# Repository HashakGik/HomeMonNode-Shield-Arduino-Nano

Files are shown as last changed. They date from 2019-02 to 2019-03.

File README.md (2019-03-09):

HomeMon Node Shield for Arduino Nano
====================================

This Eagle layout can be used to etch a single HomeMon node, in the form of a shield for the Arduino Nano prototyping platform.

The Arduino Nano sketch for this shield is available [here](https://github.com/HashakGik/HomeMonNode-Shield-Arduino-Nano).

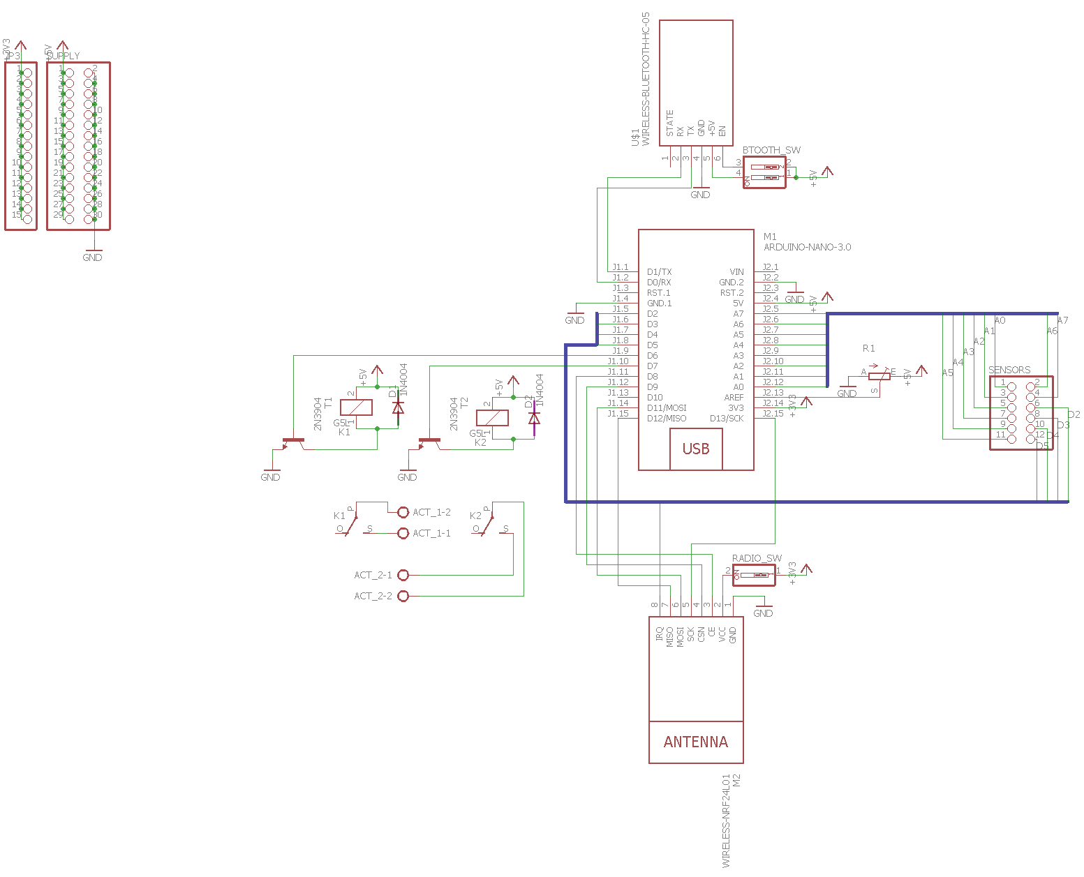
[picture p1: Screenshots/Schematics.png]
Schematics Electric scheme

<br />
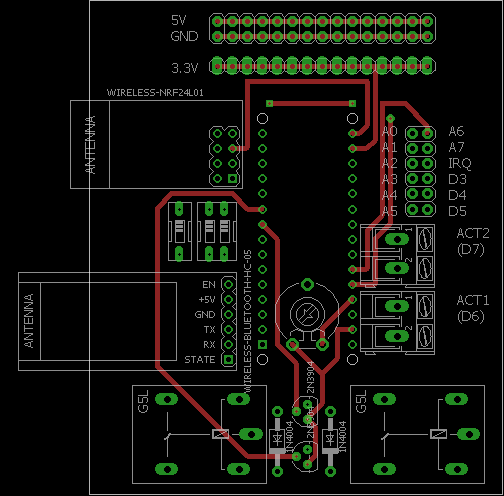
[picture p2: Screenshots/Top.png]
Top PCB Layout - Top side

<br />
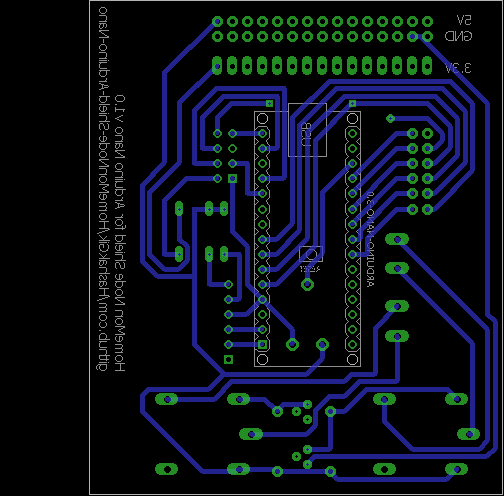
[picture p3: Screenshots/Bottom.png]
Bottom PCB Layout - Bottom side


Features
--------

- Eleven pins can be used as general I/O (e.g. for reading data from sensors)
- Two actuators can be driven by relays
- A power supply bus (5V, 3.3V and ground lines) with fifteen pins is added for convenience
- An [NRF24L01+ 2.4 GHz transceiver](https://www.nordicsemi.com/Products/Low-power-short-range-wireless/nRF24-series) is used for inter-node communication, and serial communication (either via the USB converter of the Arduino or, **optionally**, via an [HC-05 based Bluetooth adapter](https://cdn.makezine.com/uploads/2014/03/hc_hc-05-user-instructions-bluetooth.pdf) allows the node to be connected to a desktop sink running the [HomeMon Viewer Application](https://github.com/HashakGik/HomeMon-MFC-Cpp)
- A trimmer can be used to set the analog voltage reference
- Both the 2.4 GHz transceiver and the optional Bluetooth adapter can be turned on/off by switches (the Bluetooth adapter can additionally be put into AT mode for configuration purposes).

Pinout
------

- Serial pins (`D0` and `D1`): Bluetooth adapter
- SPI pins (`D11` to `D13`), `D2`, `D8` and `D9` pins: radio transceiver
- Analog pins (`A0` to `A7`): directly connected to the `SENSORS` connector
- Digital pins `D2` to `D5`: directly connected to the `SENSORS` connector. (Important note: pin `D2` is also connected to the `IRQ` pin of the transceiver)
- Digital pins `D6` and `D7`: connected to the actuator connectors (`ACT1` and `ACT2` respectively) through two relays
- `AREF`: connected to the analog reference trimmer
- `GND`, `3V3` and `5V`: connected to the power supply connectors
- `RST`, `VIN` and `D10`: unconnected.

Bill of materials
-----------------

- 1x 10k linear trimmer
- 1x Arduino Nano
- 2x Diodes with DO-41 package (e.g. 1N4004)
- 1x DIP switch SPST 1 position (RS-Components code: 877-2100)
- 2x Monostable 5V DC G5LE relays (RS-Components code: 808-8465)
- 2x NPN transistors with TO-92 package (e.g. 2N3904)
- 1x NRF24L01+ module (8 pins breakout board)
- 2x Two-ways PCB terminal blocks with 5.08mm pitch (RS-Components code: 425-8720)

Optionally, for Bluetooth support:

- 1x DIP switch SPST 2 positions (RS-Components code: 877-2113)
- 1x HC-05 Bluetooth module (6 pins breakout board)

Remarks
-------

- The shield relies on the Arduino for power supply (i.e. it doesn't have batteries nor a DC connector, energy must be supplied from the USB connector or the `VIN` pin)
- Arduino pin `D10 (SS)` is left unconnected because the SPI library may malfunction if the pin is set to high when the Arduino is acting as SPI master
- The additional components are defined in the freely available [DIYmodules.org component library](https://www.diymodules.org).

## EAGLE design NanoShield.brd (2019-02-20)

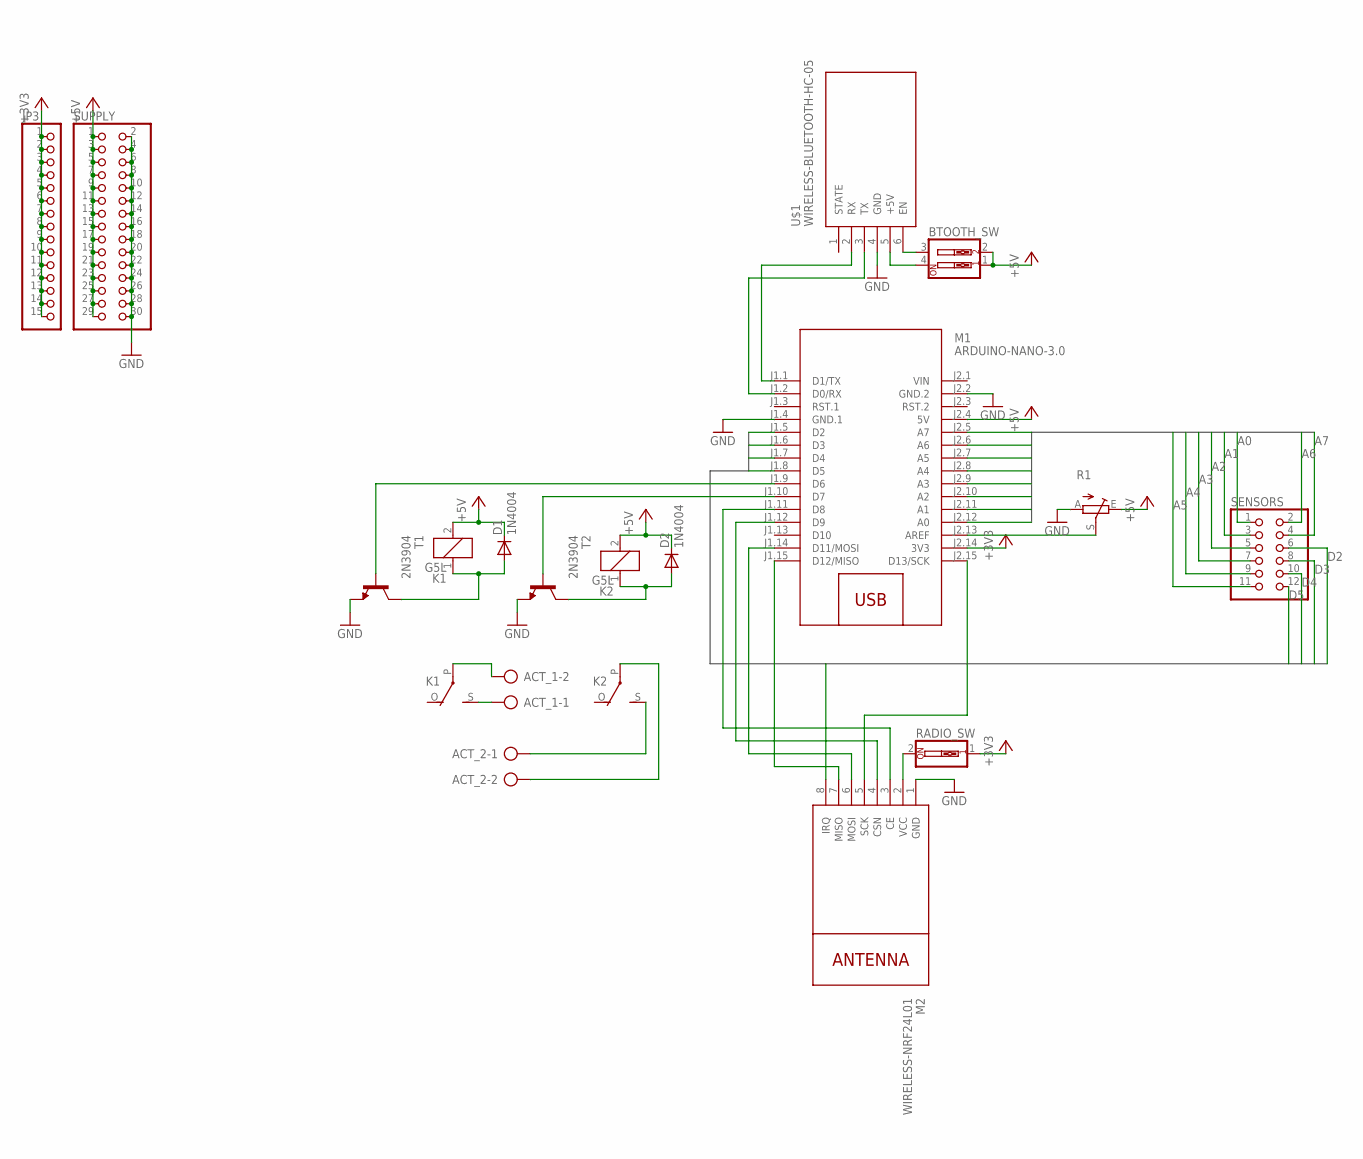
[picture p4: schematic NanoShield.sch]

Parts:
ACT_1, ACT_2: AK300/2
BTOOTH_SW: SW_DIP-2; EDG-02
D1, D2: 1N4004; DO41-10
JP3: PINHD-1X15; 1X15
K1, K2: G5L; G5LE
M1: ARDUINO-NANO-3.0
M2: WIRELESS-NRF24L01
R1: TRIM_EU-LI10; LI10
RADIO_SW: SW_DIP-1; EDG-01
SENSORS: PINHD-2X6; 2X06
SUPPLY: PINHD-2X15; 2X15
T1, T2: 2N3904; TO92
U$1: WIRELESS-BLUETOOTH-HC-05

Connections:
+3V3: JP3.1, JP3.2, JP3.3, JP3.4, JP3.5, JP3.6, JP3.7, JP3.8, JP3.9, JP3.10, JP3.11, JP3.12, JP3.13, JP3.14, JP3.15, M1.J2.14 (3V3), RADIO_SW.1
+5V: BTOOTH_SW.1, BTOOTH_SW.2, D1.C, D2.C, K1.2, K2.2, M1.J2.4 (5V), R1.E, SUPPLY.1, SUPPLY.3, SUPPLY.5, SUPPLY.7, SUPPLY.9, SUPPLY.11, SUPPLY.13, SUPPLY.15, SUPPLY.17, SUPPLY.19, SUPPLY.21, SUPPLY.23, SUPPLY.25, SUPPLY.27, SUPPLY.29
A0: M1.J2.12 (A0), SENSORS.1
A1: M1.J2.11 (A1), SENSORS.3
A2: M1.J2.10 (A2), SENSORS.5
A3: M1.J2.9 (A3), SENSORS.7
A4: M1.J2.8 (A4), SENSORS.9
A5: M1.J2.7 (A5), SENSORS.11
A6: M1.J2.6 (A6), SENSORS.2
A7: M1.J2.5 (A7), SENSORS.4
D2: M1.J1.5 (D2), M2.8 (IRQ), SENSORS.6
D3: M1.J1.6 (D3), SENSORS.8
D4: M1.J1.7 (D4), SENSORS.10
D5: M1.J1.8 (D5), SENSORS.12
GND: M1.J1.4 (GND.1), M1.J2.2 (GND.2), M2.1 (GND), R1.A, SUPPLY.2, SUPPLY.4, SUPPLY.6, SUPPLY.8, SUPPLY.10, SUPPLY.12, SUPPLY.14, SUPPLY.16, SUPPLY.18, SUPPLY.20, SUPPLY.22, SUPPLY.24, SUPPLY.26, SUPPLY.28, SUPPLY.30, T1.3 (E), T2.3 (E), U$1.4 (GND)
unnamed: M1.J2.15 (D13/SCK), M2.5 (SCK)
unnamed: M1.J1.14 (D11/MOSI), M2.6 (MOSI)
unnamed: M1.J1.15 (D12/MISO), M2.7 (MISO)
unnamed: M1.J1.1 (D1/TX), U$1.2 (RX)
unnamed: M1.J1.2 (D0/RX), U$1.3 (TX)
unnamed: M2.2 (VCC), RADIO_SW.2
unnamed: M1.J1.12 (D9), M2.4 (CSN)
unnamed: BTOOTH_SW.3, U$1.6 (EN)
unnamed: BTOOTH_SW.4, U$1.5 (+5V)
unnamed: M1.J2.13 (AREF), R1.S
unnamed: M1.J1.11 (D8), M2.3 (CE)
unnamed: M1.J1.10 (D7), T2.2 (B)
unnamed: M1.J1.9 (D6), T1.2 (B)
unnamed: D1.A, K1.1, T1.1 (C)
unnamed: ACT_1.1, K1.S
unnamed: ACT_1.2, K1.P
unnamed: D2.A, K2.1, T2.1 (C)
unnamed: ACT_2.2, K2.P
unnamed: ACT_2.1, K2.S
VIN: M1.J2.1 (VIN)

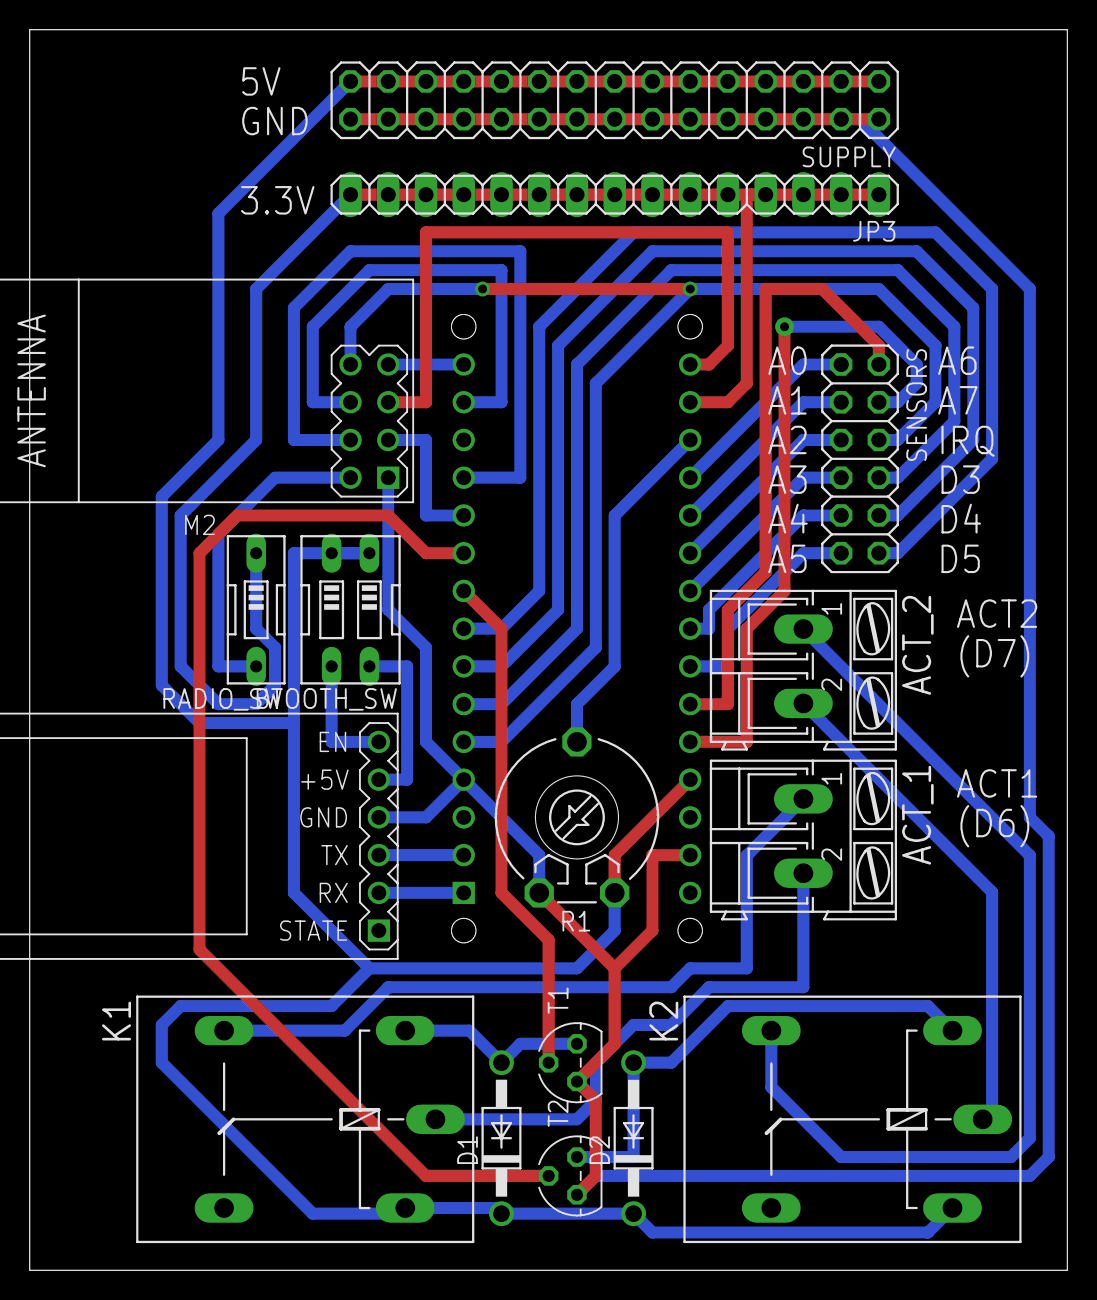
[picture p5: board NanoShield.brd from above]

Board: 2 copper layers, 69.8 x 83.5 mm, 17 parts (1 on the bottom side), 34 nets.

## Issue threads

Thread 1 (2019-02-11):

Misplaced holes

HashakGik, 2019-02-11:
The Excellon file (drd) generated by Eagle contains misplaced holes.

HashakGik, 2019-02-20:
Apparently fixed by commit 26564a780612964e64cb34c5803dfaa2b8f5a0b5

Closed 2019-02-20.

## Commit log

2019-02-11 Initial commit.
    [NanoShield.brd, NanoShield.sch]
2019-02-20 Fixed missing interrupt pin.
    [NanoShield.brd, NanoShield.sch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]
2019-03-09 Fixed bill of materials.

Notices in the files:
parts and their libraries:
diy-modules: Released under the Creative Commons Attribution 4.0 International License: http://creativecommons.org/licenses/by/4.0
